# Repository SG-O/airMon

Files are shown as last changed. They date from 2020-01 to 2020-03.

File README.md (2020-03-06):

**WARNING** This is work in progress! Expect everything to be broken!

# airMon - ESP32 based air quality monitor PCB #

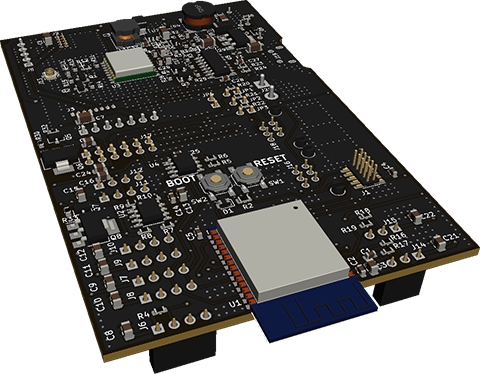
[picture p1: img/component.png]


## Features ##
### CPU ###
- Standard ESP32 WROOM module
- CH340 based USB to UART
- 802.11 b/g/n
- Bluetooth: v4.2 BR/EDR and BLE

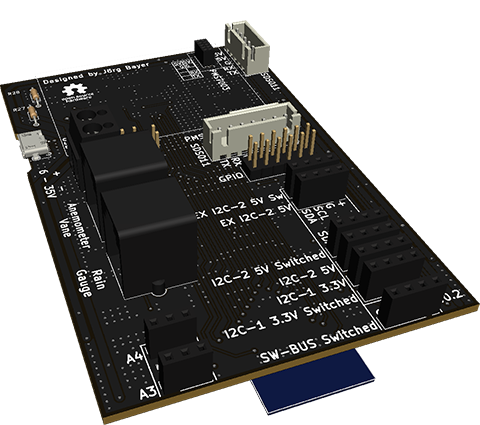
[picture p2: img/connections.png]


### IO ###
- 1 Analog IO port (0 - 12V)
- 1 Analog IO port (0 - 3.3V)
- 2 I2C buses on 4 connectors (2 of which have switchable power pins)
- 2 Additional buffered I2C connectors for longer cables (using P82B715)
- 8 GPIO
- 1 SW bus
- Dedicated connectors for several particulate matter sensors with switchable power pins
 - SDS011
 - PMS1003 - PMS6003
 - PMS7003
- Input for rainfall, wind speed and direction sensors
- GNSS support (L70/L76/MAX-M8C/MAX-M8Q/MAX-8C/MAX-8Q)
- LoRa support (RFM95/RFM96/RFM97/RFM98/RFM69)
- Input voltage measurement
- JTAG for development

### Power Supply ###
- Wide input range (6 - 35V)
- Ultra-high efficiency at light load
- Capable of 5W combined system load
- Overcurrent protection
- Customizable undervoltage protection (for battery operation)
- Switchable power outputs for high power sensors
- Reverse polarity protection

### Additional features ###
- Fits inside a 75mm waste pipe
- PMS7003 can be directly plugged into the PCB
- Active GNSS Antenna support

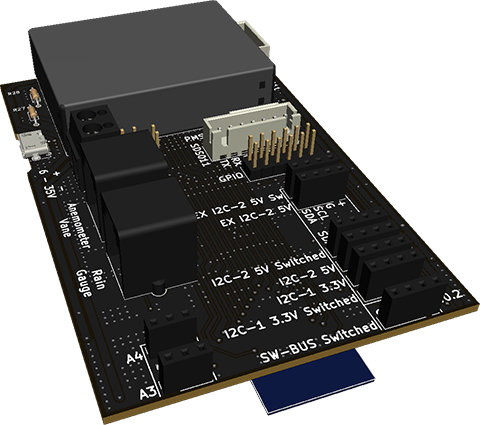
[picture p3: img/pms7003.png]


## Software ##
This was designed for the Airrohr Firmware developed by Opendata Stuttgart: [https://github.com/opendata-stuttgart/sensors-software/tree/master/airrohr-firmware](https://github.com/opendata-stuttgart/sensors-software/tree/master/airrohr-firmware)

The ESP32 support is currently experimental

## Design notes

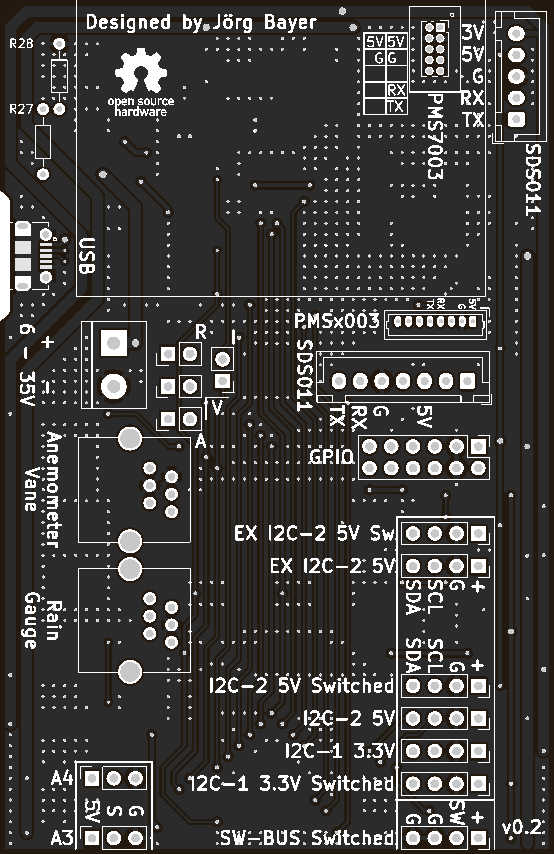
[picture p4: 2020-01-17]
img/back_nc.png

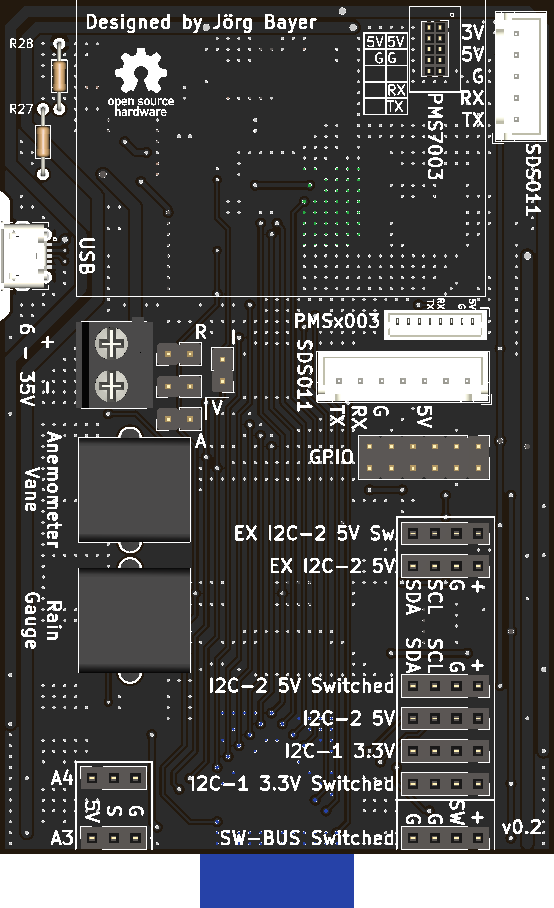
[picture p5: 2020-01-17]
img/back.png

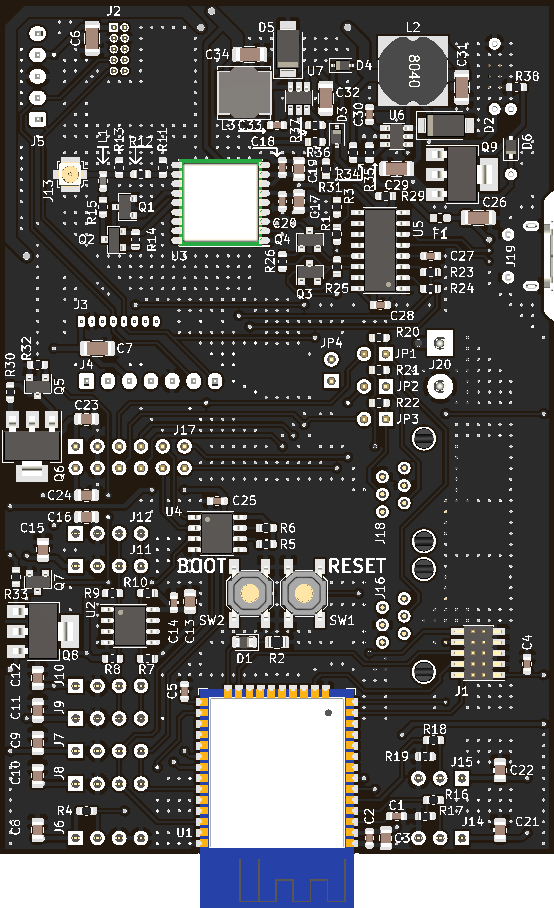
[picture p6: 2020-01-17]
img/front.png

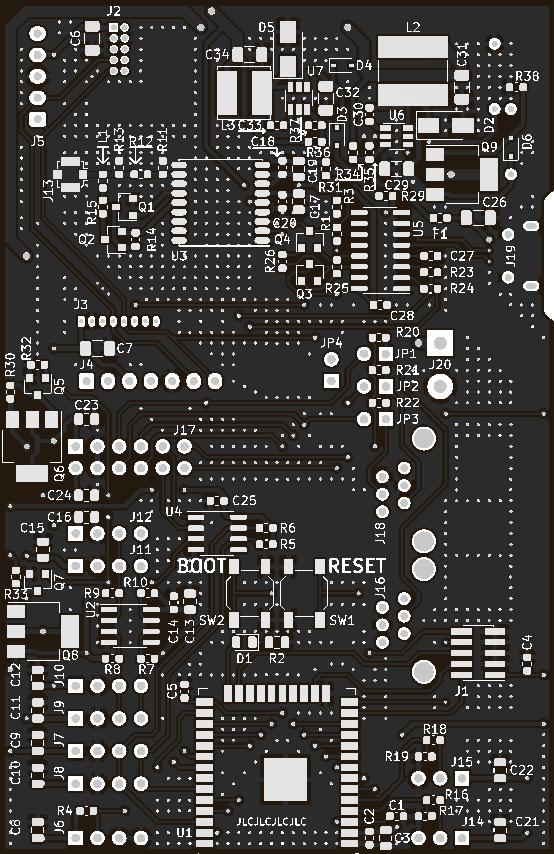
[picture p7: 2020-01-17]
img/front_nc.png

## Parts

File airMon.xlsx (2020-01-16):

Component | References | Value | Footprint | Quantity Per PCB | manf# | lcsc# | digikey#
1 | C1 C2 C4 C5 C14 C18 C20 C25 C27 C28 C30 C33 | 100n | C_0603_1608Metric | 12 | CC0603KRX7R9BB104 | C14663
2 | C6 C7 C26 C29 C31 C32 C34 | 10u | C_1206_3216Metric | 7 | CL31A106KBHNNNE | C13585
3 | C3 C8 C9 C10 C11 C12 C13 C15 C16 C17 C19 C21 C22 C23 C24 | 1u | C_0805_2012Metric | 15 | CL21B105KBFNNNE | C28323
4 | D3 D4 | BAT760-7 | D_SOD-323 | 2 | BAT760-7 | C124187
5 | D1 | GREEN | D_0805_2012Metric | 1 |  | C2297
6 | D2 D5 | SK36A-LTP | D_SMA | 2 | SK36A-LTP |  | SK36A-LTPMSCT-ND
7 | D6 | UDZVTE-1712B | D_SOD-323F | 1 | UDZVTE-1712B | C84980
8 | F1 | Polyfuse | Fuse_0603_1608Metric | 1 | 0603L050SLYR | C207014
9 | J14 | A3 | PinSocket_1x03_P2.54mm_Vertical | 1
10 | J15 | A4 | PinSocket_1x03_P2.54mm_Vertical | 1
11 | J5 | Conn_01x05 | JST_XH_B05B-XH-A_1x05_P2.50mm_Vertical | 1 | B5B-XH-A(LF)(SN) | C157991
12 | J17 | GPIO | PinHeader_2x06_P2.54mm_Vertical | 1
13 | J13 | GPS | U.FL_Molex_MCRF_73412-0110_Vertical | 1 | U.FL-R-SMT-1(80) | C88374
14 | J7 | I2C_1_1 | PinSocket_1x04_P2.54mm_Vertical | 1
15 | J8 | I2C_1_2 | PinSocket_1x04_P2.54mm_Vertical | 1
16 | J9 | I2C_2_1 | PinSocket_1x04_P2.54mm_Vertical | 1
17 | J10 | I2C_2_2 | PinSocket_1x04_P2.54mm_Vertical | 1
18 | J11 | I2C_2_3_Buffer | PinSocket_1x04_P2.54mm_Vertical | 1
19 | J12 | I2C_2_4_Buffer | PinSocket_1x04_P2.54mm_Vertical | 1
20 | J1 | JTAG | PinHeader_2x05_P1.27mm_Vertical_SMD | 1 | 20021221-00010C4LF | C180221
21 | J2 | PMS7003 | PinSocket_2x05_P1.27mm_Vertical | 1
22 | J3 | PMSx003 | Molex_PicoBlade_53047-0810_1x08_P1.25mm_Vertical | 1 | 53047-0810 | C240845
23 | J20 | Power | TerminalBlock_bornier-2_P5.08mm | 1 | WJ301V-5.0-2P | C8475
24 | J16 | Rain | DS1133-S60 | 1 | DS1133-S40BPX | C77856
25 | J4 | SDS011 | JST_XH_B07B-XH-A_1x07_P2.50mm_Vertical | 1 | B7B-XH-A(LF)(SN) | C144398
26 | J6 | SW | PinSocket_1x04_P2.54mm_Vertical | 1
27 | J19 | USB_B_Micro | USB_Micro-B_Molex-105017-0001 | 1 | 105017-0001 | C136000
28 | J18 | Wind | DS1133-S60 | 1 | DS1133-S40BPX | C77856
29 | JP1 JP2 JP3 JP4 | Jumper_NO | PinHeader_1x02_P2.54mm_Vertical | 4
30 | L3 | 15uH | L_Bourns_SRN6045TA | 1 | SRN6045-150M |  | SRN6045-150MCT-ND
31 | L2 | 22uH | L_Bourns_SRN8040 | 1 | SRN8040-220M |  | SRN8040-220MCT-ND
32 | L1 | 47n | L_0603_1608Metric | 1 | SDCL1608C47NJTDF | C29683
33 | Q1 Q5 Q7 | 2N7002 | SOT-23 | 3 | 2N7002 | C8545
34 | Q2 | AO3401A | SOT-23 | 1 | AO3401A | C15127
35 | Q6 Q8 Q9 | DMP6023LE-13 | SOT-223-3_TabPin2 | 3 | DMP6023LE-13 | C154901
36 | Q3 Q4 | SS8050 | SOT-23 | 2 | SS8050 | C2150
37 | R12 | 0R | R_0603_1608Metric | 1 | 0603WAF0000T5E | C21189
38 | R30 R32 R33 | 100k | R_0603_1608Metric | 3 | 0603WAF1003T5E | C25803
39 | R15 | 10R | R_0603_1608Metric | 1 | 0603WAF100JT5E | C22859
40 | R1 R3 R4 R14 R21 R25 R26 R31 | 10k | R_0603_1608Metric | 8 | 0603WAF1002T5E | C25804
41 | R29 R34 R36 | 110k | R_0603_1608Metric | 3 | RT0603BRD07110KL | C326736
42 | R17 R19 | 15k | R_0603_1608Metric | 2 | 0603WAF1502T5E | C22809
43 | R38 | 1M | R_0603_1608Metric | 1 | 0603WAF1004T5E | C22935
44 | R2 | 1k | R_0805_2012Metric | 1 | 0805W8F1001T5E | C17513
45 | R35 | 20k | R_0603_1608Metric | 1 | ERJPB3B2002V | C191225
46 | R9 R10 | 330R | R_0603_1608Metric | 2 | 0603WAF3300T5E | C23138
47 | R37 | 33k | R_0603_1608Metric | 1 | ERJ3RBD3302V | C416700
48 | R23 R24 | 470R | R_0603_1608Metric | 2 | 0603WAF4700T5E | C23179
49 | R16 R18 | 47k | R_0603_1608Metric | 2 | 0603WAF4702T5E | C25819
50 | R5 R6 R7 R8 R20 R22 | 4k7 | R_0603_1608Metric | 6 | 0603WAF4701T5E | C23162
53 | SW2 | Boot | SW_SPST_SKQG_WithStem | 1 | TS-1187A-C-C-B | C318889
54 | SW1 | RESET | SW_SPST_SKQG_WithStem | 1 | TS-1187A-C-C-B | C318889
55 | U5 | CH340C | SOIC-16_3.9x9.9mm_P1.27mm | 1 | CH340C | C84681
56 | U1 | ESP32-WROOM-32 | ESP32-WROOM-32 | 1 | ESP32-WROOM-32
57 | U3 | L70/L76/MAX-M8C/MAX-M8Q/MAX-8C/MAX-8Q | L70 | 1
58 | U6 U7 | LMR14010ADDCR | TSOT-23-6 | 2 | LMR14010ADDCR | C388174
59 | U2 | P82B715 | SOIC-8_3.9x4.9mm_P1.27mm | 1 | P82B715 |  | 296-24729-1-ND
60 | U4 | PCA9536D | SOIC-8_3.9x4.9mm_P1.27mm | 1 | PCA9536D | C129522

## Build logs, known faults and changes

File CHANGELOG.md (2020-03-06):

# Changelog #
## v0.3 ##

- Fixed a swapped I2C bus

## v0.2 ##

- Added RFM95 Module for Lora
- Changed input voltage monitoring from A2(IO35) to A3(IO36)
- Removed A3 12V compatibility
- Rearranged IOs to fit new components

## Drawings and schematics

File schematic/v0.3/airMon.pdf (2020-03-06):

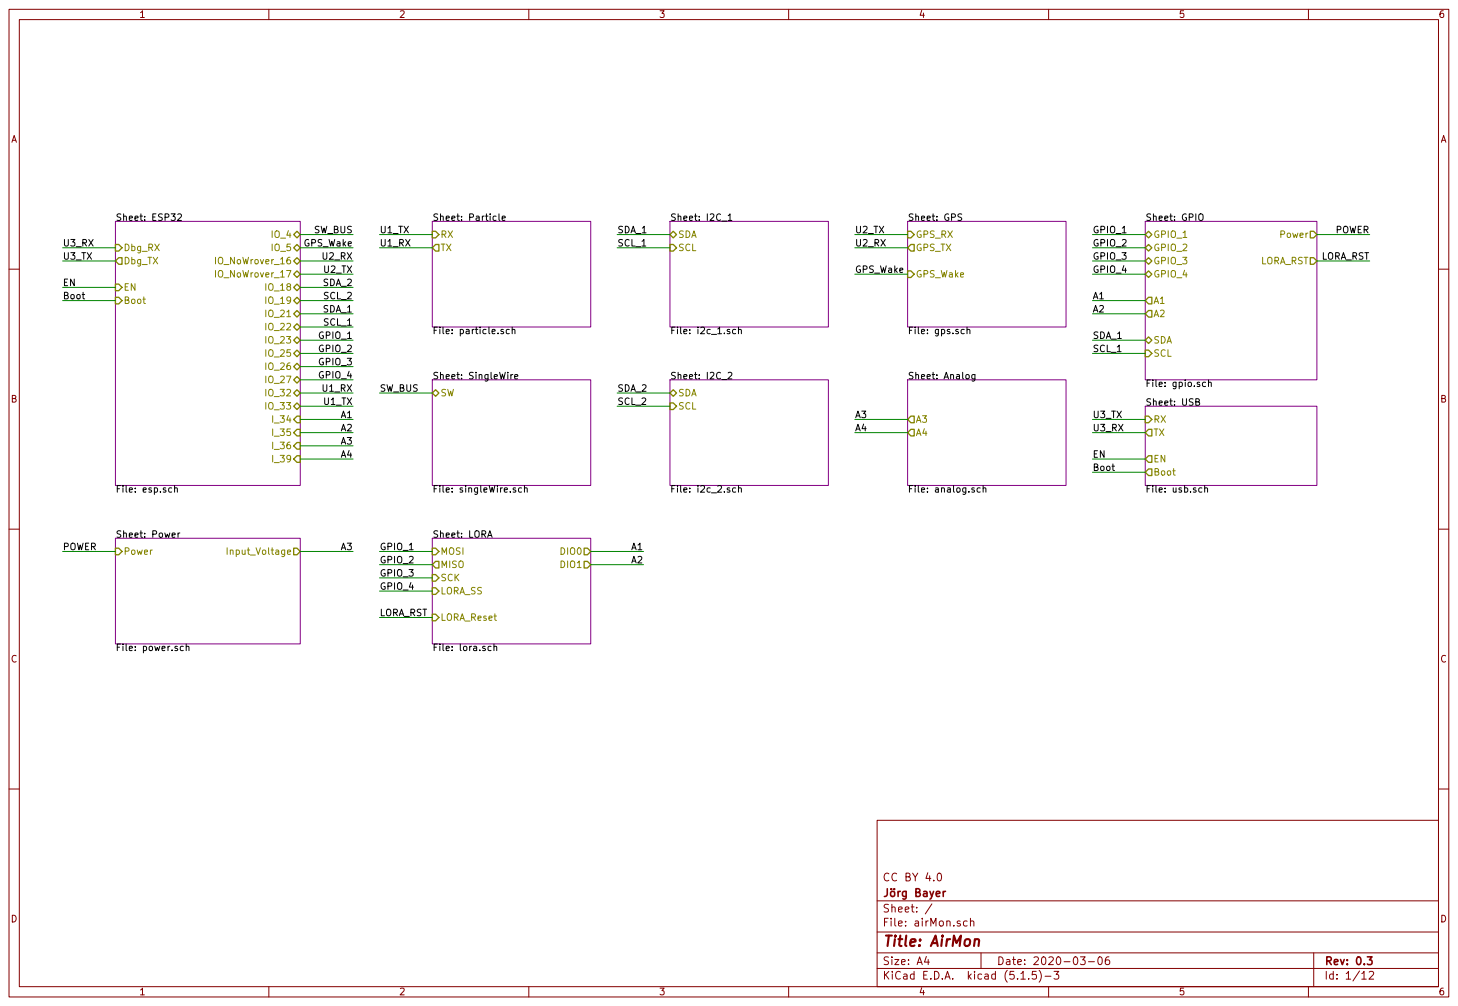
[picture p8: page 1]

Sheet: ESP32 File: esp.sch

Sheet: Particle File: particle.sch RX

Sheet: I2C_1 File: i2c_1.sch SCL SDA
File: gps.sch GPS_RX GPS_TX GPS_Wake Sheet: I2C_2 File: i2c_2.sch SCL SDA

Sheet: SingleWire
File: singleWire.sch SW

File: usb.sch EN

File: lora.sch SCK MOSI MISO

File: airMon.sch Sheet: / Jörg Bayer CC BY 4.0

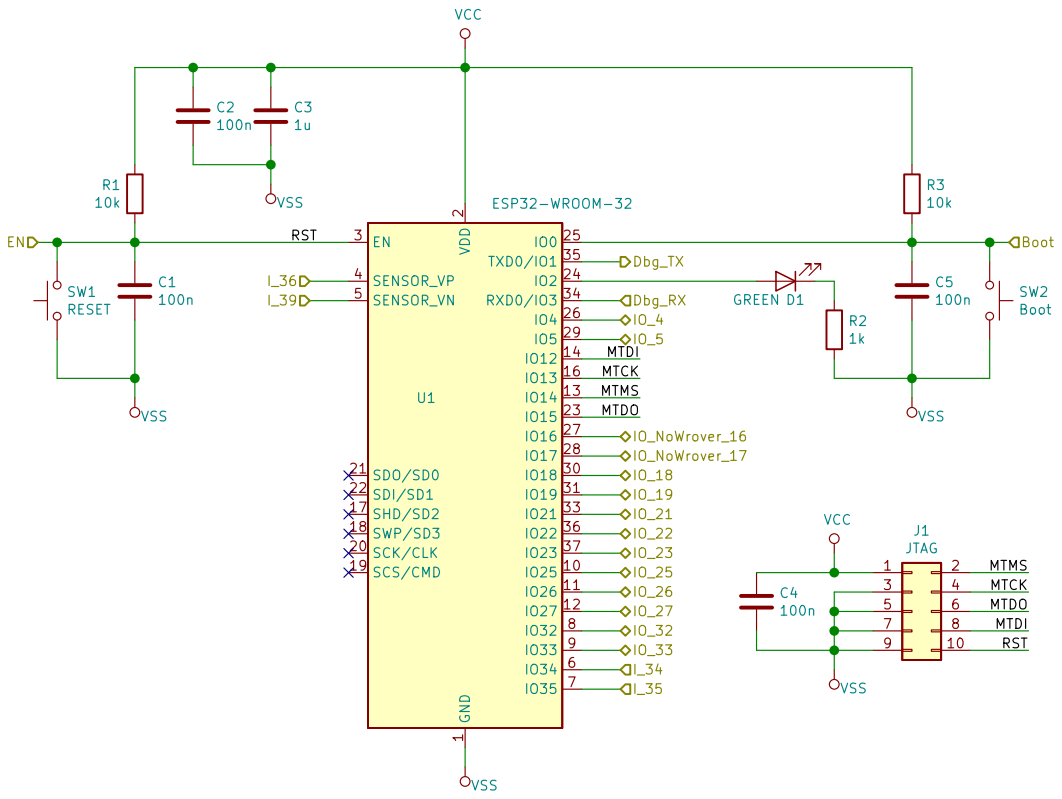
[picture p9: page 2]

2 SCK/CLK 20 SDO/SD0 21 SDI/SD1 22

File: esp.sch Sheet: /ESP32/ Jörg Bayer CC BY 4.0 C4

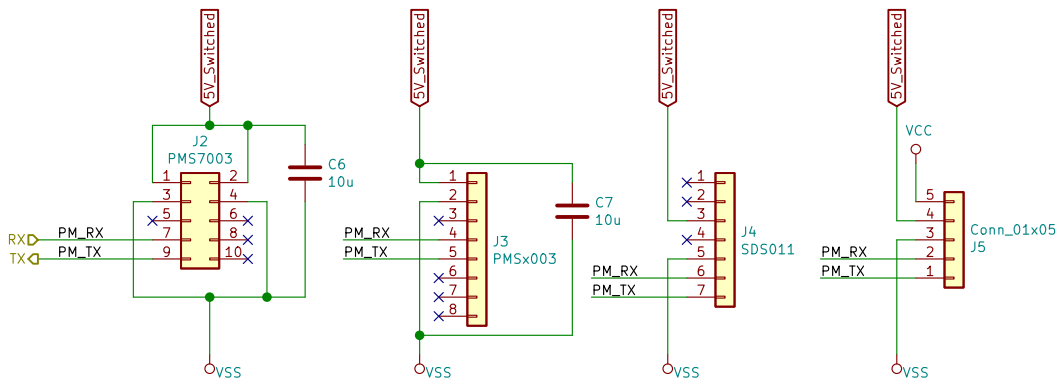
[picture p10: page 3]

File: particle.sch Sheet: /Particle/ Jörg Bayer CC BY 4.0

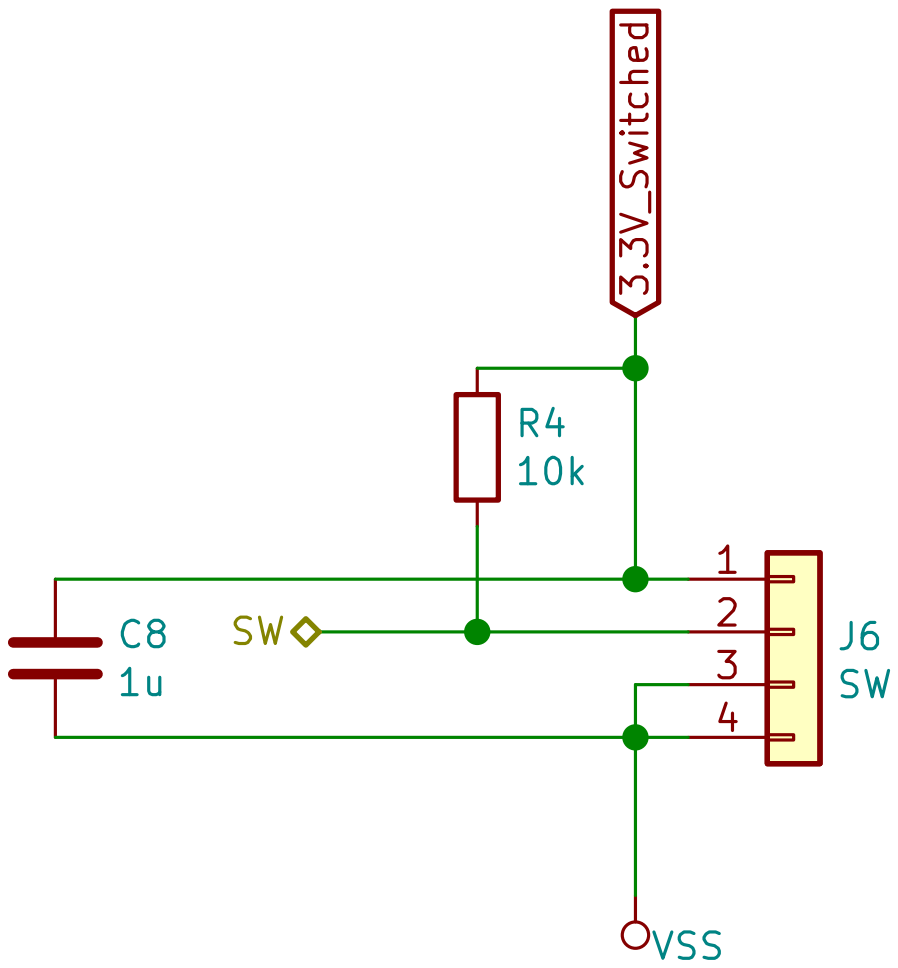
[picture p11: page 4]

Jörg Bayer CC BY 4.0

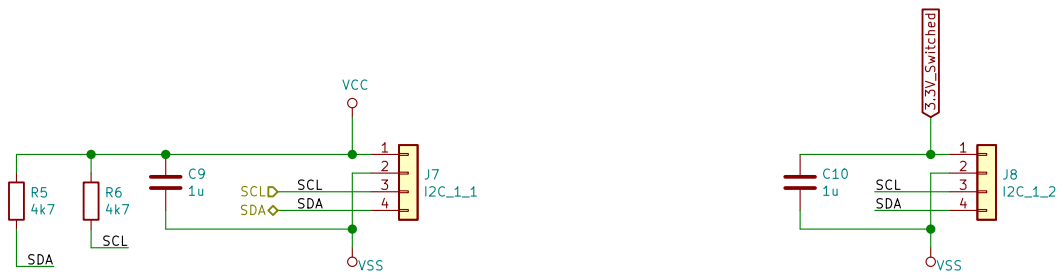
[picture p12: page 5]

Jörg Bayer CC BY 4.0

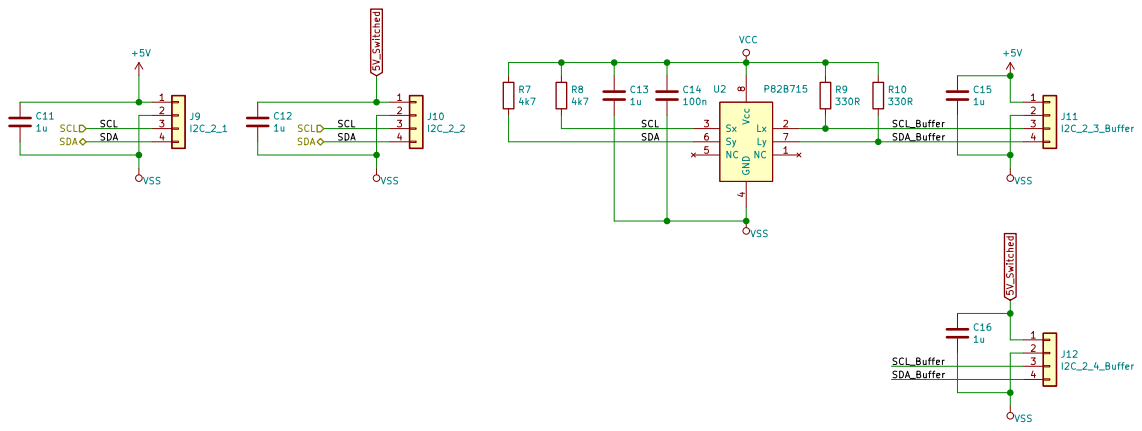
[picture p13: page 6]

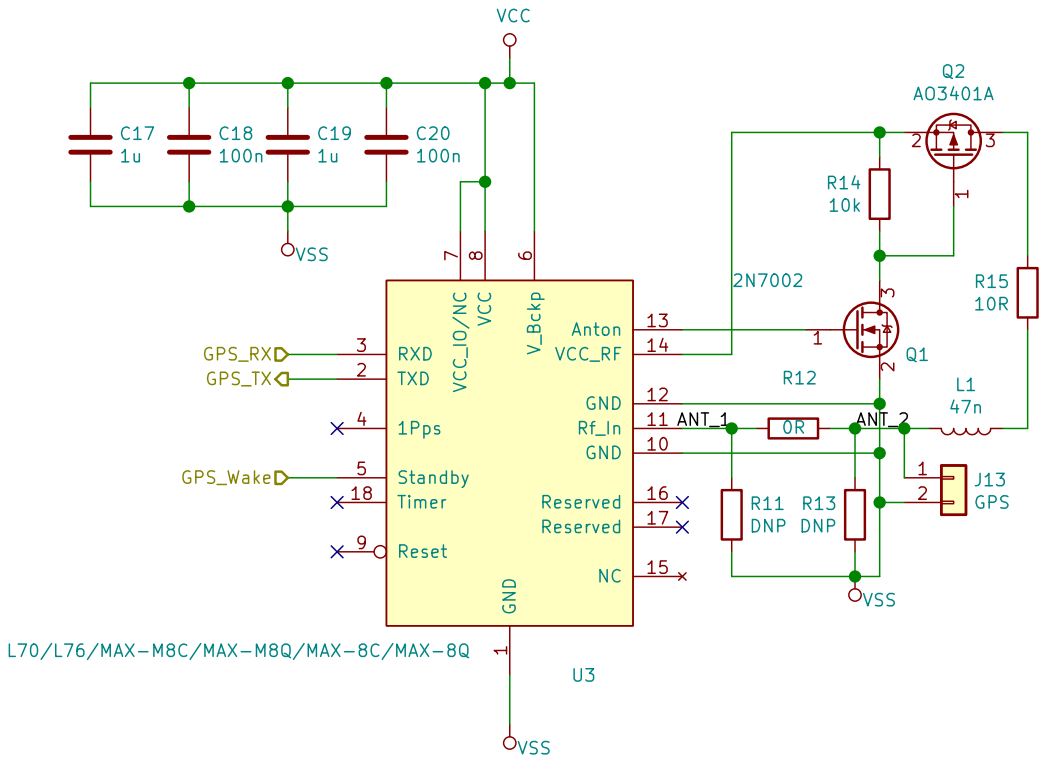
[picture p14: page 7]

File: gps.sch Sheet: /GPS/ Jörg Bayer CC BY 4.0 R13 DNP

1 GND 10 Rf_In 11 GND 12 Anton 13 VCC_RF 14 NC 15 Reserved 16 Reserved 17 Timer 18 TXD 2 RXD 3

L70/L76/MAX-M8C/MAX-M8Q/MAX-8C/MAX-8Q

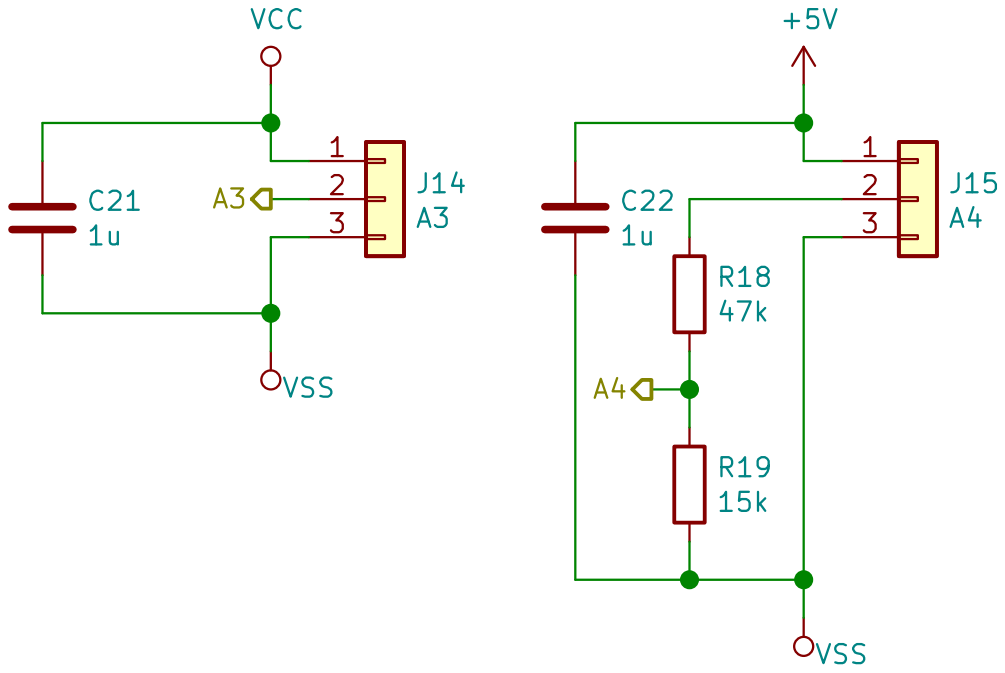
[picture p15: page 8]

Jörg Bayer CC BY 4.0

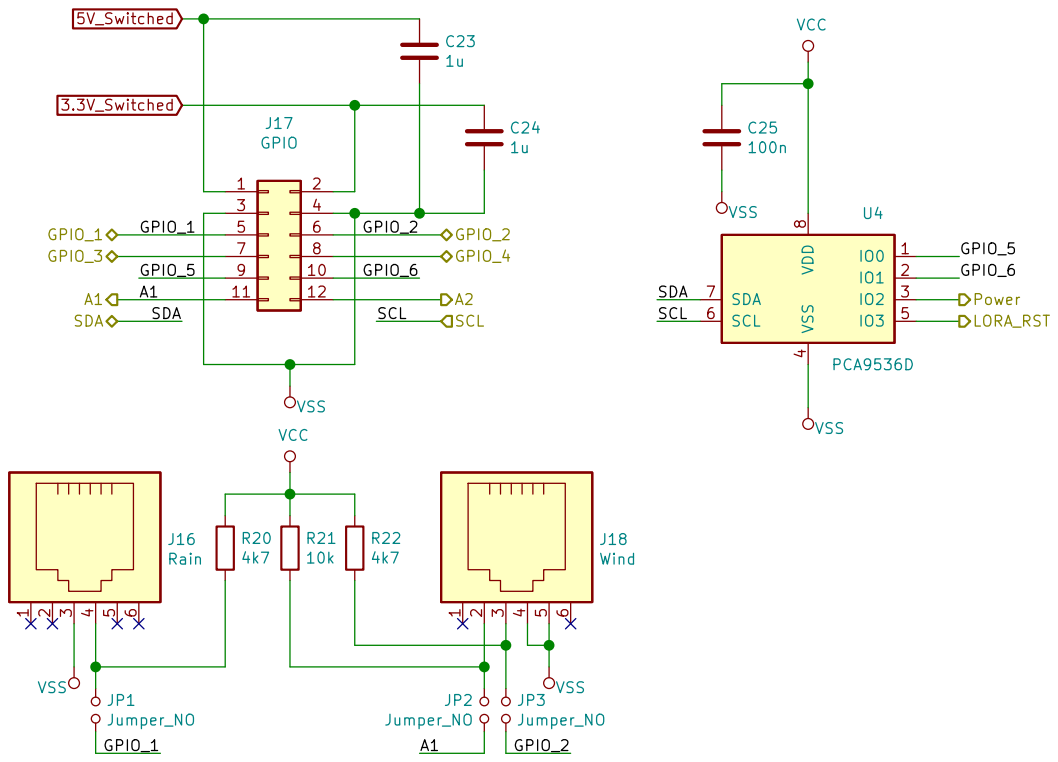
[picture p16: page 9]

9 | 10
11 | 12

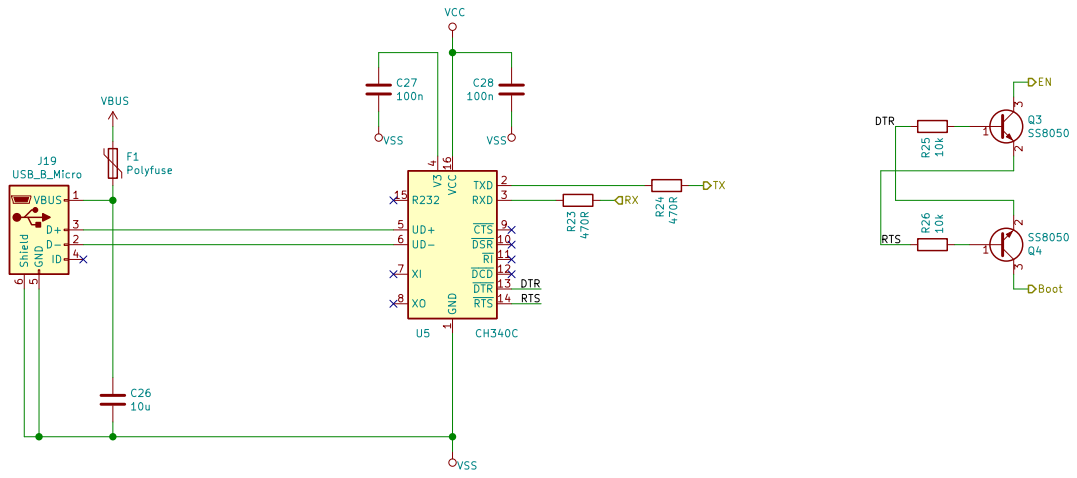
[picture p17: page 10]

1 DSR 10 RI 11 DCD 12 DTR 13 RTS 14 R232 15 VCC 16 TXD 2 RXD 3 V3

4 UD+ 5 UD- 6 XI 7 XO 8 CTS 9 U5 CH340C R24 470R R23 470R

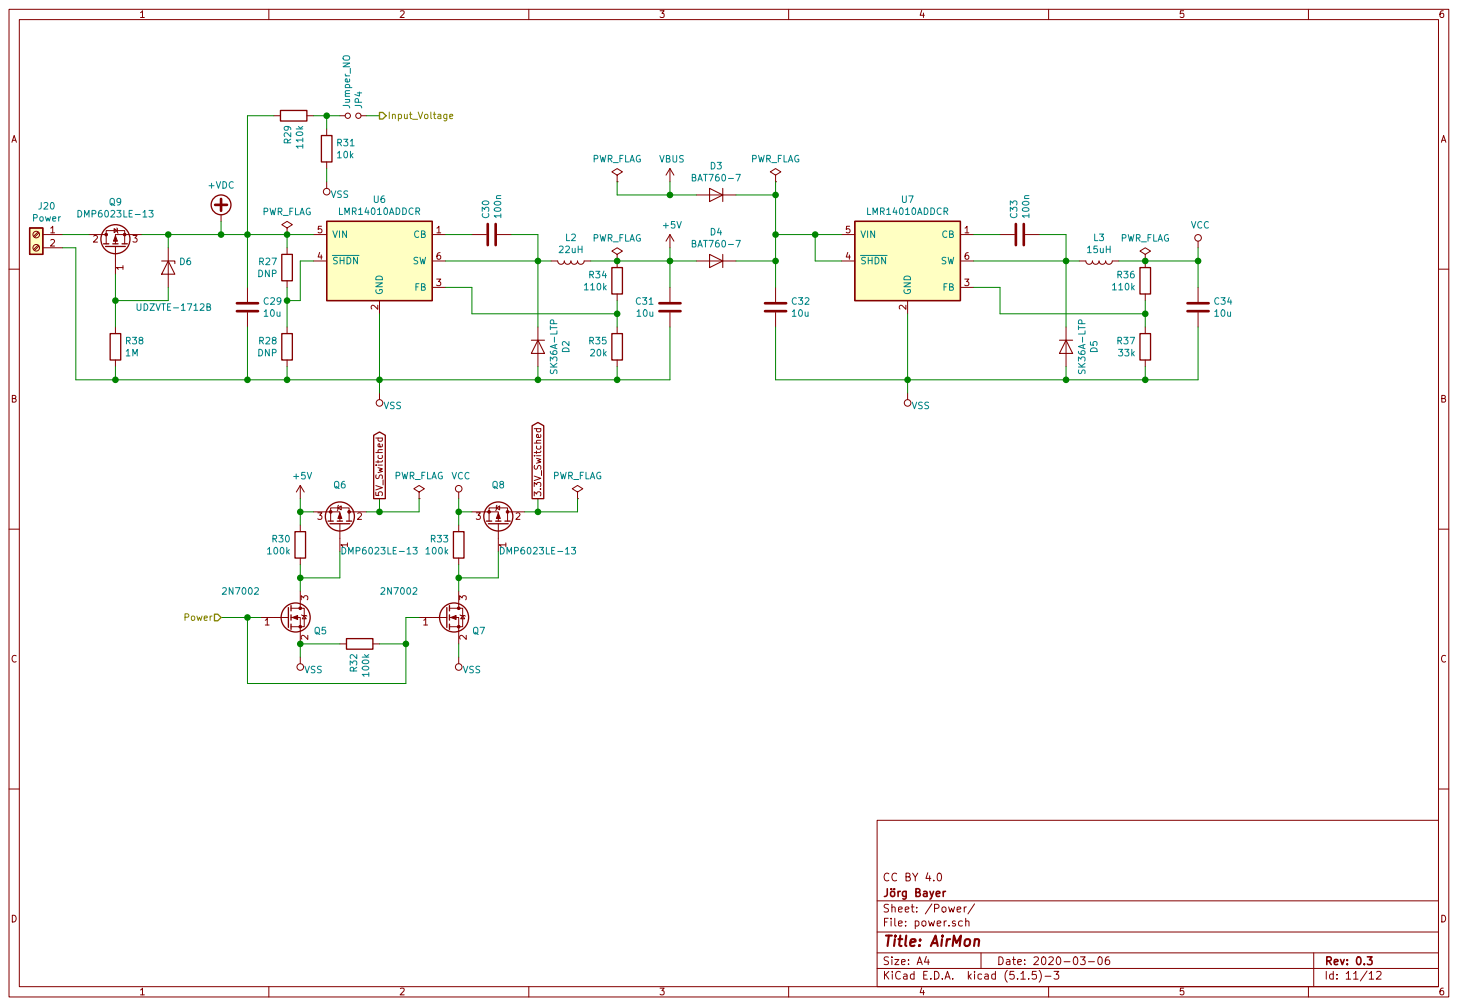
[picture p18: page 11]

2 FB 3 SHDN 4 VIN 5 SW 6 U6

2 FB 3 SHDN 4 VIN 5 SW 6 U7
LMR14010ADDCR

File: power.sch Sheet: /Power/ Jörg Bayer CC BY 4.0 PWR_FLAG

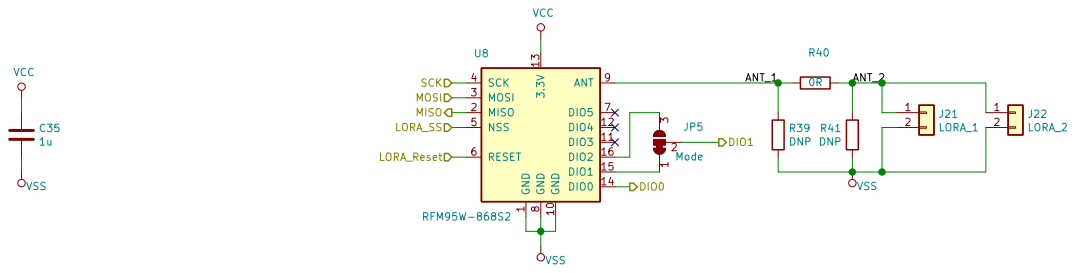
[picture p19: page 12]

1 GND 10 DIO3 11 DIO4 12 3.3V 13 DIO0 14 DIO1 15 DIO2 16 MISO 2 MOSI 3 SCK 4 NSS 5 RESET 6 DIO5 7 GND

Id: 12/12 Title: File: lora.sch Sheet: /LORA/ GND

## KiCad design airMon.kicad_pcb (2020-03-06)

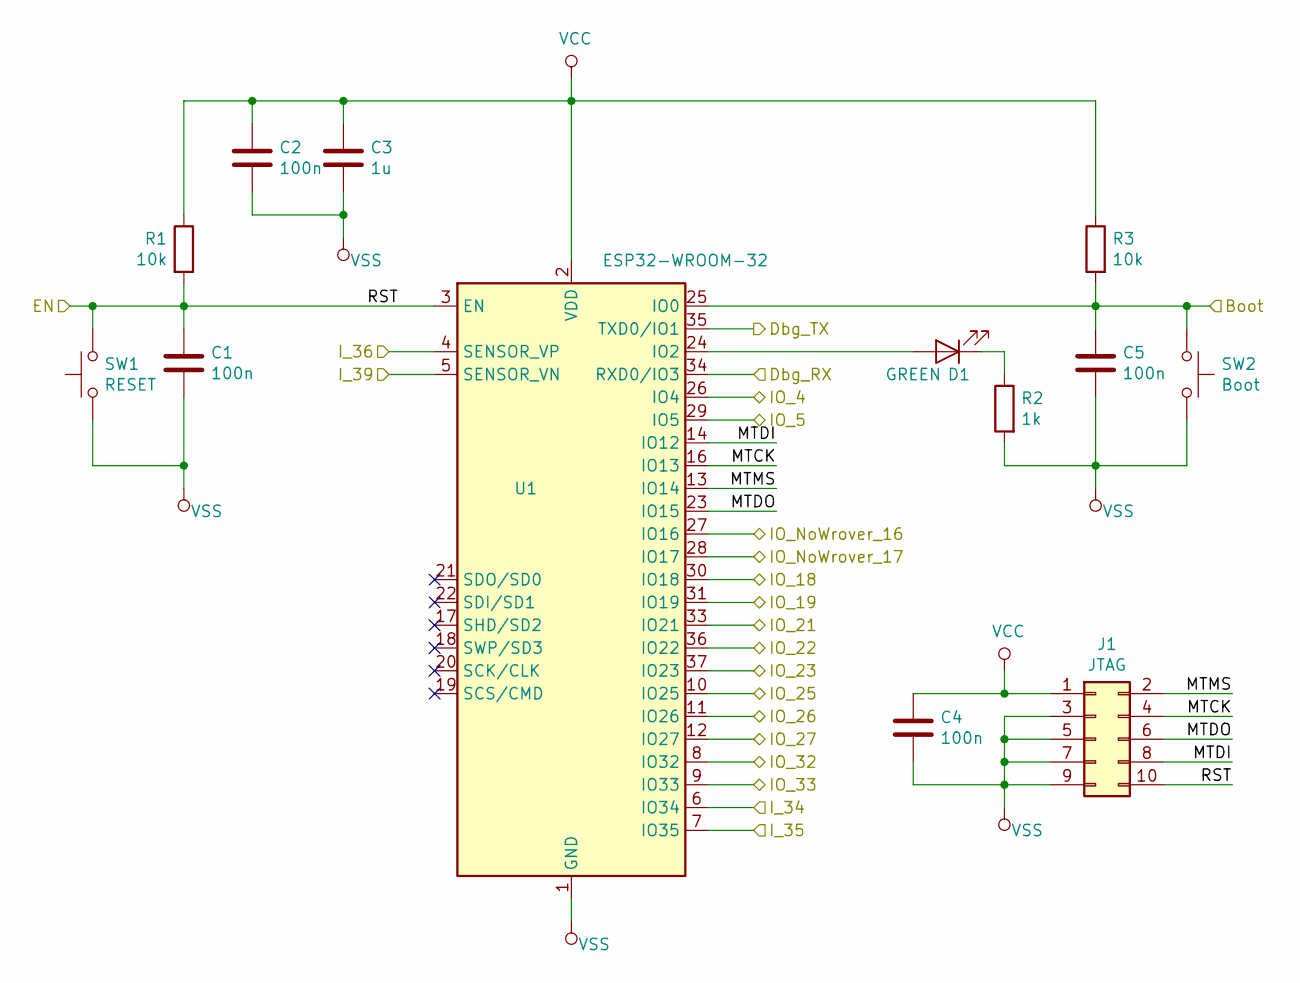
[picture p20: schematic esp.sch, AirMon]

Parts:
C1, C2, C4, C5: 100n; C_0603_1608Metric; lcsc# C14663
C3: 1u; C_0805_2012Metric; lcsc# C28323
D1: GREEN; D_0805_2012Metric; lcsc# C2297
J1: JTAG; PinHeader_2x05_P1.27mm_Vertical_SMD; lcsc# C180221
R1, R3: 10k; R_0603_1608Metric; lcsc# C25804
R2: 1k; R_0805_2012Metric; lcsc# C17513
SW1: RESET; SW_SPST_SKQG_WithStem; lcsc# C318889
SW2: Boot; SW_SPST_SKQG_WithStem; lcsc# C318889
U1: ESP32-WROOM-32

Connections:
/A1: U1.6 (IO34); also elsewhere on the board
/A2: U1.7 (IO35); also elsewhere on the board
/A3: U1.4 (SENSOR_VP); also elsewhere on the board
/A4: U1.5 (SENSOR_VN); also elsewhere on the board
/Boot: C5.1, R3.2, SW2.1, U1.25 (IO0); also elsewhere on the board
/EN: C1.1, J1.10, R1.2, SW1.1, U1.3 (EN); also elsewhere on the board
/ESP32/MTCK: J1.4, U1.16 (IO13)
/ESP32/MTDI: J1.8, U1.14 (IO12)
/ESP32/MTDO: J1.6, U1.23 (IO15)
/ESP32/MTMS: J1.2, U1.13 (IO14)
/GPIO_1: U1.37 (IO23); also elsewhere on the board
/GPIO_2: U1.10 (IO25); also elsewhere on the board
/GPIO_3: U1.11 (IO26); also elsewhere on the board
/GPIO_4: U1.12 (IO27); also elsewhere on the board
/GPS_Wake: U1.29 (IO5); also elsewhere on the board
/SCL_1: U1.36 (IO22); also elsewhere on the board
/SCL_2: U1.31 (IO19); also elsewhere on the board
/SDA_1: U1.33 (IO21); also elsewhere on the board
/SDA_2: U1.30 (IO18); also elsewhere on the board
/SW_BUS: U1.26 (IO4); also elsewhere on the board
/U1_RX: U1.8 (IO32); also elsewhere on the board
/U1_TX: U1.9 (IO33); also elsewhere on the board
/U2_RX: U1.27 (IO16); also elsewhere on the board
/U2_TX: U1.28 (IO17); also elsewhere on the board
/U3_RX: U1.34 (RXD0/IO3); also elsewhere on the board
/U3_TX: U1.35 (TXD0/IO1); also elsewhere on the board
unnamed: D1.1 (K), R2.1
unnamed: D1.2 (A), U1.24 (IO2)
VCC: C2.1, C3.1, C4.1, J1.1, R1.1, R3.1, U1.2 (VDD); also elsewhere on the board
VSS: C1.2, C2.2, C3.2, C4.2, C5.2, J1.3, J1.5, J1.7, J1.9, R2.2, SW1.2, SW2.2, U1.1 (GND), U1.15 (GND), U1.38 (GND), U1.39 (GND); also elsewhere on the board

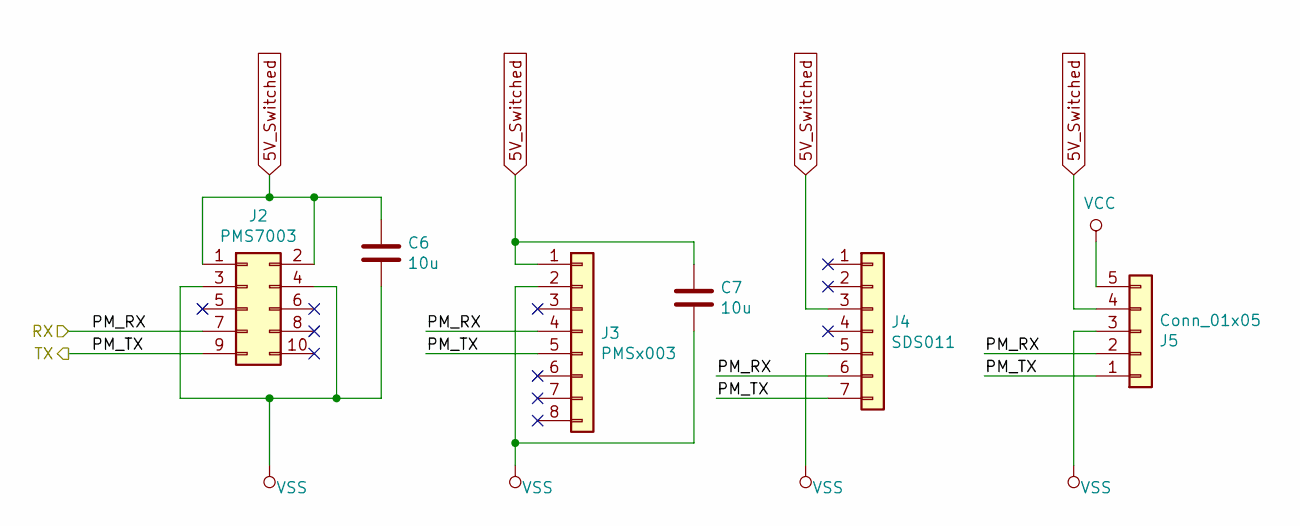
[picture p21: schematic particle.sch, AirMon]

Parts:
C6, C7: 10u; C_1206_3216Metric; lcsc# C13585
J2: PMS7003; PinSocket_2x05_P1.27mm_Vertical
J3: PMSx003; Molex_PicoBlade_53047-0810_1x08_P1.25mm_Vertical; lcsc# C240845
J4: SDS011; JST_XH_B07B-XH-A_1x07_P2.50mm_Vertical; lcsc# C144398
J5: Conn_01x05; JST_XH_B05B-XH-A_1x05_P2.50mm_Vertical; lcsc# C157991

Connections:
5V_Switched: C6.1, C7.1, J2.1, J2.2, J3.1, J4.3, J5.4; also elsewhere on the board
/U1_RX: J2.9, J3.5, J4.7, J5.1; also elsewhere on the board
/U1_TX: J2.7, J3.4, J4.6, J5.2; also elsewhere on the board
VCC: J5.5; also elsewhere on the board
VSS: C6.2, C7.2, J2.3, J2.4, J3.2, J4.5, J5.3; also elsewhere on the board

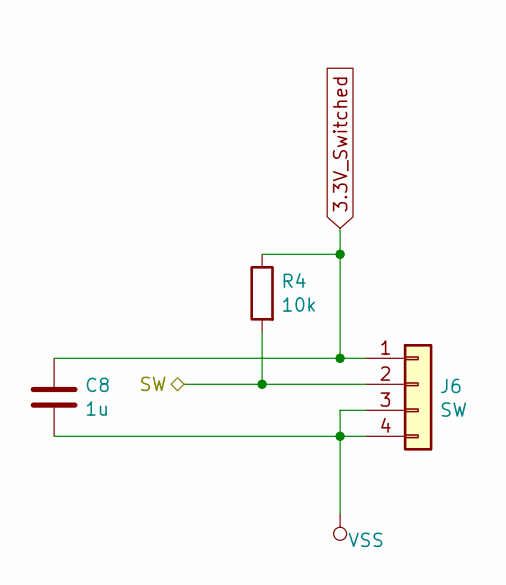
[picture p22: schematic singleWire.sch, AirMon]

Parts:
C8: 1u; C_0805_2012Metric; lcsc# C28323
J6: SW; PinSocket_1x04_P2.54mm_Vertical
R4: 10k; R_0603_1608Metric; lcsc# C25804

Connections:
3.3V_Switched: C8.1, J6.1, R4.1; also elsewhere on the board
/SW_BUS: J6.2, R4.2; also elsewhere on the board
VSS: C8.2, J6.3, J6.4; also elsewhere on the board

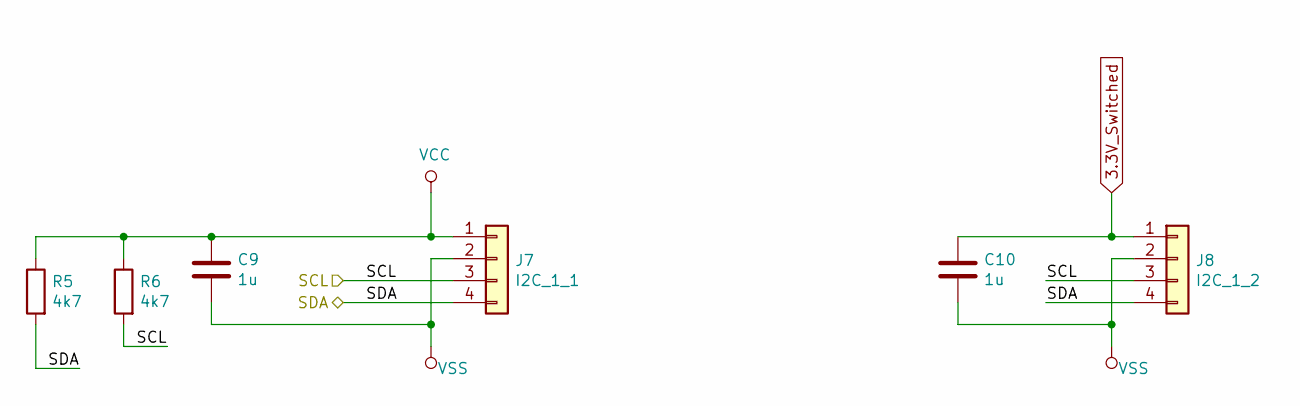
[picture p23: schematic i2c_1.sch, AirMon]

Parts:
C9, C10: 1u; C_0805_2012Metric; lcsc# C28323
J7: I2C_1_1; PinSocket_1x04_P2.54mm_Vertical
J8: I2C_1_2; PinSocket_1x04_P2.54mm_Vertical
R5, R6: 4k7; R_0603_1608Metric; lcsc# C23162

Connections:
3.3V_Switched: C10.1, J8.1; also elsewhere on the board
/SCL_1: J7.3, J8.3, R6.2; also elsewhere on the board
/SDA_1: J7.4, J8.4, R5.2; also elsewhere on the board
VCC: C9.1, J7.1, R5.1, R6.1; also elsewhere on the board
VSS: C9.2, C10.2, J7.2, J8.2; also elsewhere on the board

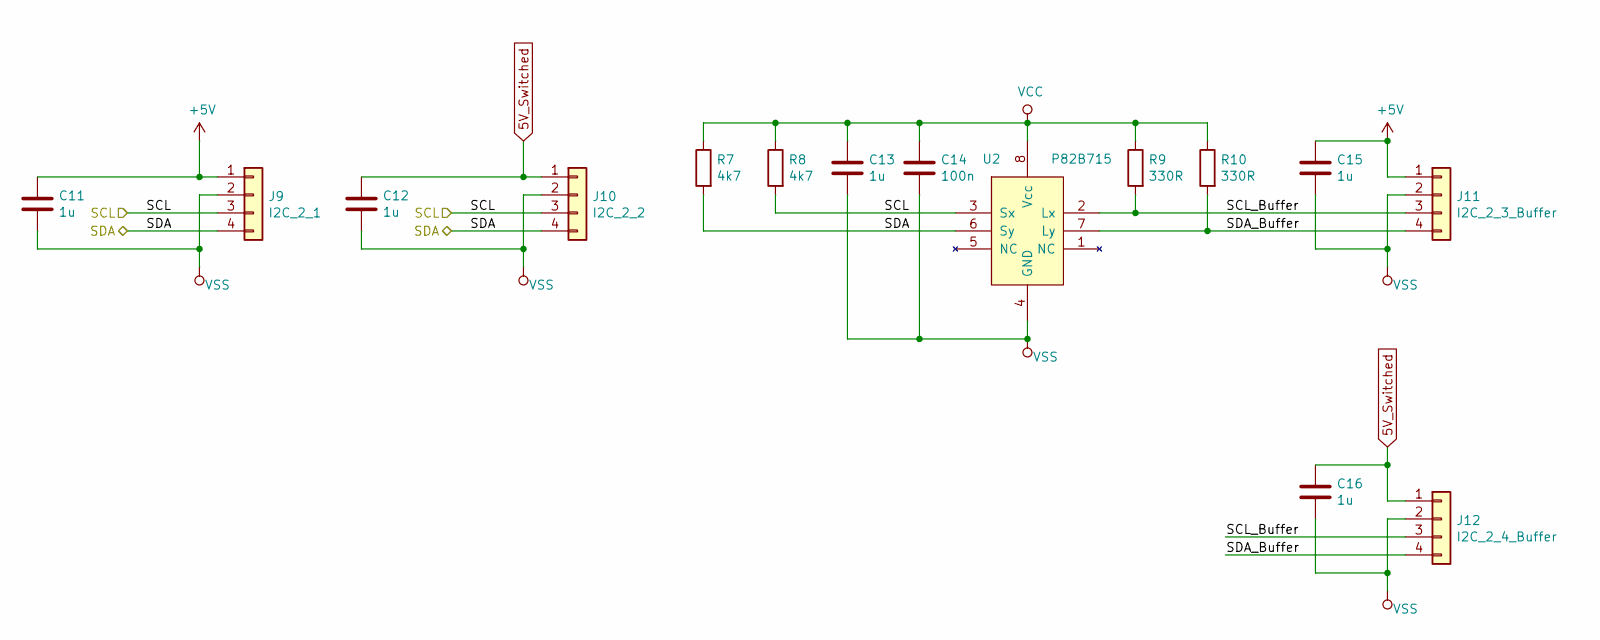
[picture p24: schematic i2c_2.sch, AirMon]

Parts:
C11, C12, C13, C15, C16: 1u; C_0805_2012Metric; lcsc# C28323
C14: 100n; C_0603_1608Metric; lcsc# C14663
J9: I2C_2_1; PinSocket_1x04_P2.54mm_Vertical
J10: I2C_2_2; PinSocket_1x04_P2.54mm_Vertical
J11: I2C_2_3_Buffer; PinSocket_1x04_P2.54mm_Vertical
J12: I2C_2_4_Buffer; PinSocket_1x04_P2.54mm_Vertical
R7, R8: 4k7; R_0603_1608Metric; lcsc# C23162
R9, R10: 330R; R_0603_1608Metric; lcsc# C23138
U2: P82B715; SOIC-8_3.9x4.9mm_P1.27mm; digikey# 296-24729-1-ND

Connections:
5V_Switched: C12.1, C16.1, J10.1, J12.1; also elsewhere on the board
+5V: C11.1, C15.1, J9.1, J11.1; also elsewhere on the board
/I2C_2/SCL_Buffer: J11.3, J12.3, R9.2, U2.2 (Lx)
/I2C_2/SDA_Buffer: J11.4, J12.4, R10.2, U2.7 (Ly)
/SCL_2: J9.3, J10.3, R8.2, U2.3 (Sx); also elsewhere on the board
/SDA_2: J9.4, J10.4, R7.2, U2.6 (Sy); also elsewhere on the board
VCC: C13.1, C14.1, R7.1, R8.1, R9.1, R10.1, U2.8 (Vcc); also elsewhere on the board
VSS: C11.2, C12.2, C13.2, C14.2, C15.2, C16.2, J9.2, J10.2, J11.2, J12.2, U2.4 (GND); also elsewhere on the board

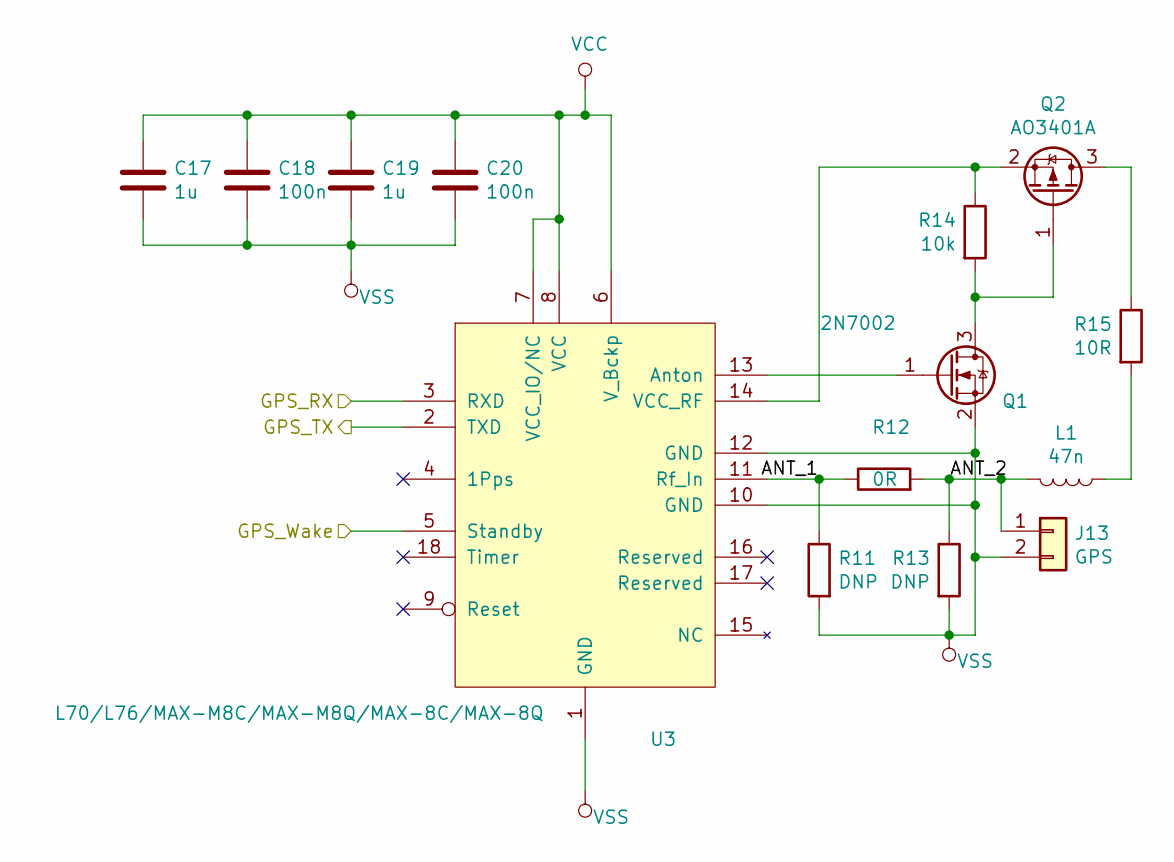
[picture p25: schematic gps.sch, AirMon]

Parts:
C17, C19: 1u; C_0805_2012Metric; lcsc# C28323
C18, C20: 100n; C_0603_1608Metric; lcsc# C14663
J13: GPS; U.FL_Molex_MCRF_73412-0110_Vertical; lcsc# C88374
L1: 47n; L_0603_1608Metric; lcsc# C29683
Q1: 2N7002; SOT-23; lcsc# C8545
Q2: AO3401A; SOT-23; lcsc# C15127
R11, R13: DNP; R_0603_1608Metric
R12: 0R; R_0603_1608Metric; lcsc# C21189
R14: 10k; R_0603_1608Metric; lcsc# C25804
R15: 10R; R_0603_1608Metric; lcsc# C22859
U3: L70/L76/MAX-M8C/MAX-M8Q/MAX-8C/MAX-8Q; L70

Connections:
/GPS/ANT_1: R11.1, R12.1, U3.11 (Rf_In)
/GPS/ANT_2: J13.1, L1.2, R12.2, R13.1
/GPS_Wake: U3.5 (Standby); also elsewhere on the board
/U2_RX: U3.2 (TXD); also elsewhere on the board
/U2_TX: U3.3 (RXD); also elsewhere on the board
unnamed: L1.1, R15.2
unnamed: Q1.1 (G), U3.13 (Anton)
unnamed: Q1.3 (D), Q2.1 (G), R14.2
unnamed: Q2.2 (S), R14.1, U3.14 (VCC_RF)
unnamed: Q2.3 (D), R15.1
VCC: C17.1, C18.1, C19.1, C20.1, U3.6 (V_Bckp), U3.7 (VCC_IO/NC), U3.8 (VCC); also elsewhere on the board
VSS: C17.2, C18.2, C19.2, C20.2, J13.2, Q1.2 (S), R11.2, R13.2, U3.1 (GND), U3.10 (GND), U3.12 (GND); also elsewhere on the board

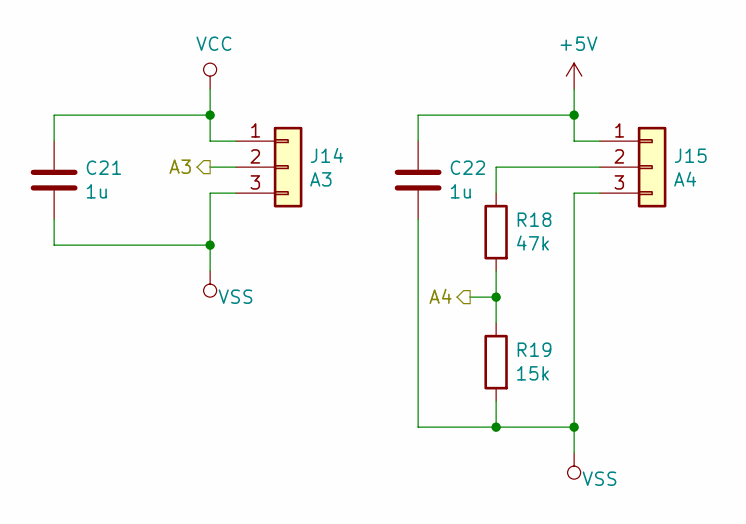
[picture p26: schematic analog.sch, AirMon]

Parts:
C21, C22: 1u; C_0805_2012Metric; lcsc# C28323
J14: A3; PinSocket_1x03_P2.54mm_Vertical
J15: A4; PinSocket_1x03_P2.54mm_Vertical
R18: 47k; R_0603_1608Metric; lcsc# C25819
R19: 15k; R_0603_1608Metric; lcsc# C22809

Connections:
+5V: C22.1, J15.1; also elsewhere on the board
/A3: J14.2; also elsewhere on the board
/A4: R18.2, R19.1; also elsewhere on the board
unnamed: J15.2, R18.1
VCC: C21.1, J14.1; also elsewhere on the board
VSS: C21.2, C22.2, J14.3, J15.3, R19.2; also elsewhere on the board

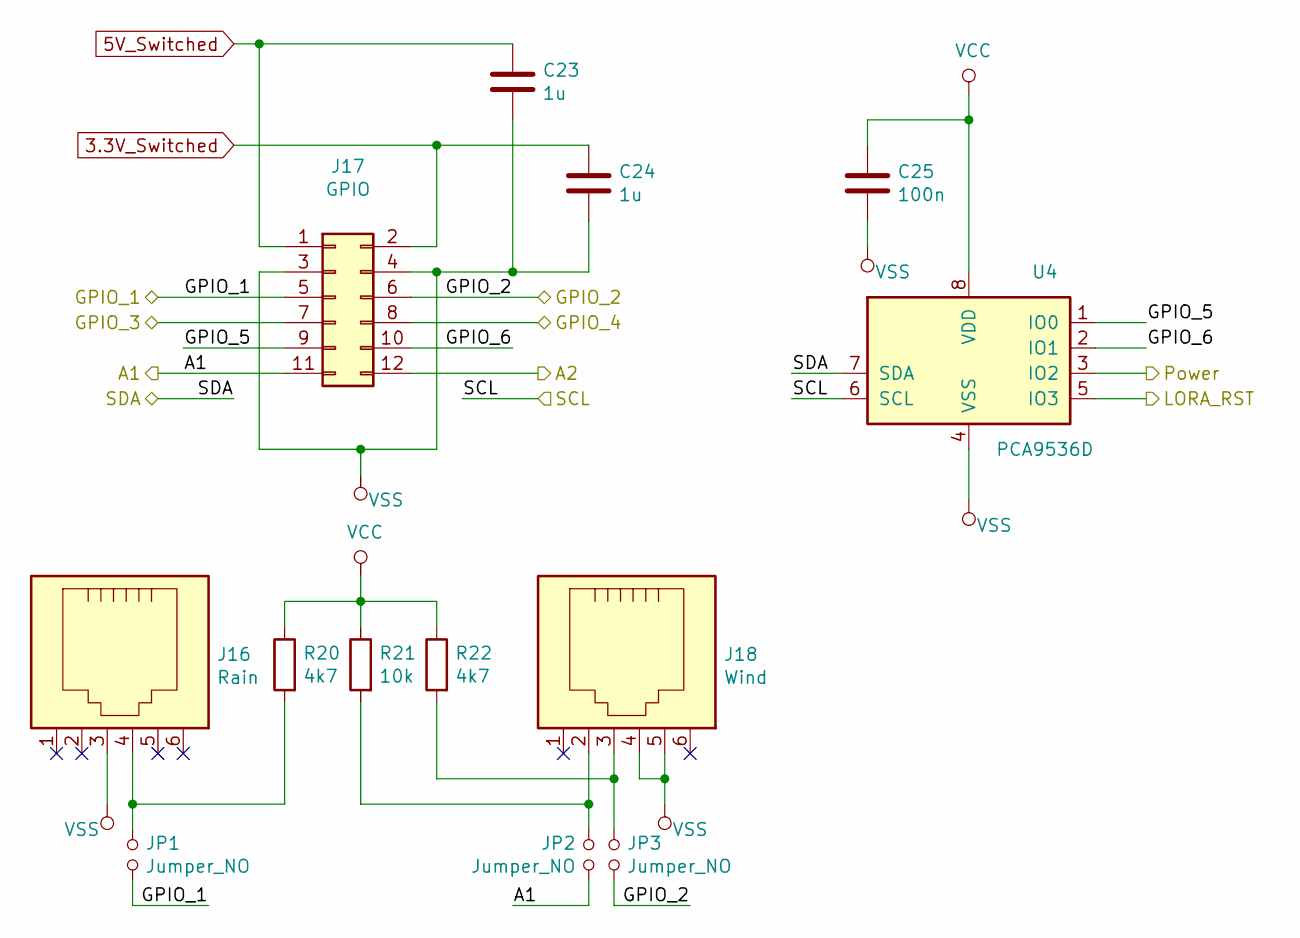
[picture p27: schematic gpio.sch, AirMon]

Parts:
C23, C24: 1u; C_0805_2012Metric; lcsc# C28323
C25: 100n; C_0603_1608Metric; lcsc# C14663
J16: Rain; DS1133-S60; lcsc# C77856
J17: GPIO; PinHeader_2x06_P2.54mm_Vertical
J18: Wind; DS1133-S60; lcsc# C77856
JP1, JP2, JP3: Jumper_NO; PinHeader_1x02_P2.54mm_Vertical
R20, R22: 4k7; R_0603_1608Metric; lcsc# C23162
R21: 10k; R_0603_1608Metric; lcsc# C25804
U4: PCA9536D; SOIC-8_3.9x4.9mm_P1.27mm; lcsc# C129522

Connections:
3.3V_Switched: C24.1, J17.2; also elsewhere on the board
5V_Switched: C23.1, J17.1; also elsewhere on the board
/A1: J17.11, JP2.2; also elsewhere on the board
/A2: J17.12; also elsewhere on the board
/GPIO/GPIO_5: J17.9, U4.1 (IO0)
/GPIO/GPIO_6: J17.10, U4.2 (IO1)
/GPIO_1: J17.5, JP1.2; also elsewhere on the board
/GPIO_2: J17.6, JP3.2; also elsewhere on the board
/GPIO_3: J17.7; also elsewhere on the board
/GPIO_4: J17.8; also elsewhere on the board
/LORA_RST: U4.5 (IO3); also elsewhere on the board
/POWER: U4.3 (IO2); also elsewhere on the board
/SCL_1: U4.6 (SCL); also elsewhere on the board
/SDA_1: U4.7 (SDA); also elsewhere on the board
unnamed: J16.4, JP1.1, R20.2
unnamed: J18.2, JP2.1, R21.2
unnamed: J18.3, JP3.1, R22.2
VCC: C25.1, R20.1, R21.1, R22.1, U4.8 (VDD); also elsewhere on the board
VSS: C23.2, C24.2, C25.2, J16.3, J17.3, J17.4, J18.4, J18.5, U4.4 (VSS); also elsewhere on the board

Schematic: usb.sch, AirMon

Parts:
C26: 10u; C_1206_3216Metric; lcsc# C13585
C27, C28: 100n; C_0603_1608Metric; lcsc# C14663
F1: Polyfuse; Fuse_0603_1608Metric; lcsc# C207014
J19: USB_B_Micro; USB_Micro-B_Molex-105017-0001; lcsc# C136000
Q3, Q4: SS8050; SOT-23; lcsc# C2150
R23, R24: 470R; R_0603_1608Metric; lcsc# C23179
R25, R26: 10k; R_0603_1608Metric; lcsc# C25804
U5: CH340C; SOIC-16_3.9x9.9mm_P1.27mm; lcsc# C84681

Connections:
/Boot: Q4.3 (C); also elsewhere on the board
/EN: Q3.3 (C); also elsewhere on the board
/U3_RX: R24.2; also elsewhere on the board
/U3_TX: R23.2; also elsewhere on the board
/USB/DTR: Q4.2 (E), R25.1, U5.13 (~DTR)
/USB/RTS: Q3.2 (E), R26.1, U5.14 (~RTS)
unnamed: C26.1, F1.2, J19.1 (VBUS)
unnamed: C27.1, U5.4 (V3)
unnamed: J19.2 (D-), U5.6 (UD-)
unnamed: J19.3 (D+), U5.5 (UD+)
unnamed: Q3.1 (B), R25.2
unnamed: Q4.1 (B), R26.2
unnamed: R23.1, U5.3 (RXD)
unnamed: R24.1, U5.2 (TXD)
VBUS: F1.1; also elsewhere on the board
VCC: C28.1, U5.16 (VCC); also elsewhere on the board
VSS: C26.2, C27.2, C28.2, J19.5 (GND), J19.6 (Shield), U5.1 (GND); also elsewhere on the board

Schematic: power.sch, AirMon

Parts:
C29, C31, C32, C34: 10u; C_1206_3216Metric; lcsc# C13585
C30, C33: 100n; C_0603_1608Metric; lcsc# C14663
D2, D5: SK36A-LTP; D_SMA; digikey# SK36A-LTPMSCT-ND
D3, D4: BAT760-7; D_SOD-323; lcsc# C124187
D6: UDZVTE-1712B; D_SOD-323F; lcsc# C84980
J20: Power; TerminalBlock_bornier-2_P5.08mm; lcsc# C8475
JP4: Jumper_NO; PinHeader_1x02_P2.54mm_Vertical
L2: 22uH; L_Bourns_SRN8040; digikey# SRN8040-220MCT-ND
L3: 15uH; L_Bourns_SRN6045TA; digikey# SRN6045-150MCT-ND
Q5, Q7: 2N7002; SOT-23; lcsc# C8545
Q6, Q8, Q9: DMP6023LE-13; SOT-223-3_TabPin2; lcsc# C154901
R27, R28: DNP; R_Axial_DIN0204_L3.6mm_D1.6mm_P7.62mm_Horizontal
R29, R34, R36: 110k; R_0603_1608Metric; lcsc# C326736
R30, R32, R33: 100k; R_0603_1608Metric; lcsc# C25803
R31: 10k; R_0603_1608Metric; lcsc# C25804
R35: 20k; R_0603_1608Metric; lcsc# C191225
R37: 33k; R_0603_1608Metric; lcsc# C416700
R38: 1M; R_0603_1608Metric; lcsc# C22935
U6, U7: LMR14010ADDCR; TSOT-23-6; lcsc# C388174

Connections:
3.3V_Switched: Q8.2 (D); also elsewhere on the board
5V_Switched: Q6.2 (D); also elsewhere on the board
+5V: C31.1, D4.2 (A), L2.1, Q6.3 (S), R30.1, R34.1; also elsewhere on the board
+VDC: C29.1, D6.1 (K), Q9.3 (S), R27.1, R29.1, U6.5 (VIN)
/A3: JP4.1; also elsewhere on the board
/POWER: Q5.1 (G), Q7.1 (G), R32.2; also elsewhere on the board
unnamed: C30.1, U6.1 (CB)
unnamed: C30.2, D2.1 (K), L2.2, U6.6 (SW)
unnamed: C32.1, D3.1 (K), D4.1 (K), U7.4 (~SHDN), U7.5 (VIN)
unnamed: C33.1, U7.1 (CB)
unnamed: C33.2, D5.1 (K), L3.2, U7.6 (SW)
unnamed: D6.2 (A), Q9.1 (G), R38.1
unnamed: J20.1, Q9.2 (D)
unnamed: JP4.2, R29.2, R31.1
unnamed: Q5.3 (D), Q6.1 (G), R30.2
unnamed: Q7.3 (D), Q8.1 (G), R33.2
unnamed: R27.2, R28.1, U6.4 (~SHDN)
unnamed: R34.2, R35.1, U6.3 (FB)
unnamed: R36.2, R37.1, U7.3 (FB)
VBUS: D3.2 (A); also elsewhere on the board
VCC: C34.1, L3.1, Q8.3 (S), R33.1, R36.1; also elsewhere on the board
VSS: C29.2, C31.2, C32.2, C34.2, D2.2 (A), D5.2 (A), J20.2, Q5.2 (S), Q7.2 (S), R28.2, R31.2, R32.1, R35.2, R37.2, R38.2, U6.2 (GND), U7.2 (GND); also elsewhere on the board

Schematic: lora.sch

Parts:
C35: 1u; C_0805_2012Metric; lcsc# C28323
J21: LORA_1; U.FL_Molex_MCRF_73412-0110_Vertical; lcsc# C88374
J22: LORA_2; PinHeader_1x02_P1.27mm_Vertical
JP5: Mode; SolderJumper-3_P1.3mm_Bridged12_RoundedPad1.0x1.5mm_NumberL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
R39, R41: DNP; R_0603_1608Metric
R40: 0R; R_0603_1608Metric; lcsc# C21189
U8: RFM95W-868S2; HOPERF_RFM9XW_SMD

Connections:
/A1: U8.14 (DIO0); also elsewhere on the board
/A2: JP5.2 (C); also elsewhere on the board
/GPIO_1: U8.3 (MOSI); also elsewhere on the board
/GPIO_2: U8.2 (MISO); also elsewhere on the board
/GPIO_3: U8.4 (SCK); also elsewhere on the board
/GPIO_4: U8.5 (NSS); also elsewhere on the board
/LORA/ANT_1: R39.1, R40.1, U8.9 (ANT)
/LORA/ANT_2: J21.1, J22.1, R40.2, R41.1
/LORA_RST: U8.6 (RESET); also elsewhere on the board
unnamed: JP5.1 (A), U8.15 (DIO1)
unnamed: JP5.3 (B), U8.16 (DIO2)
VCC: C35.1, U8.13 (3.3V); also elsewhere on the board
VSS: C35.2, J21.2, J22.2, R39.2, R41.2, U8.1 (GND), U8.8 (GND), U8.10 (GND); also elsewhere on the board

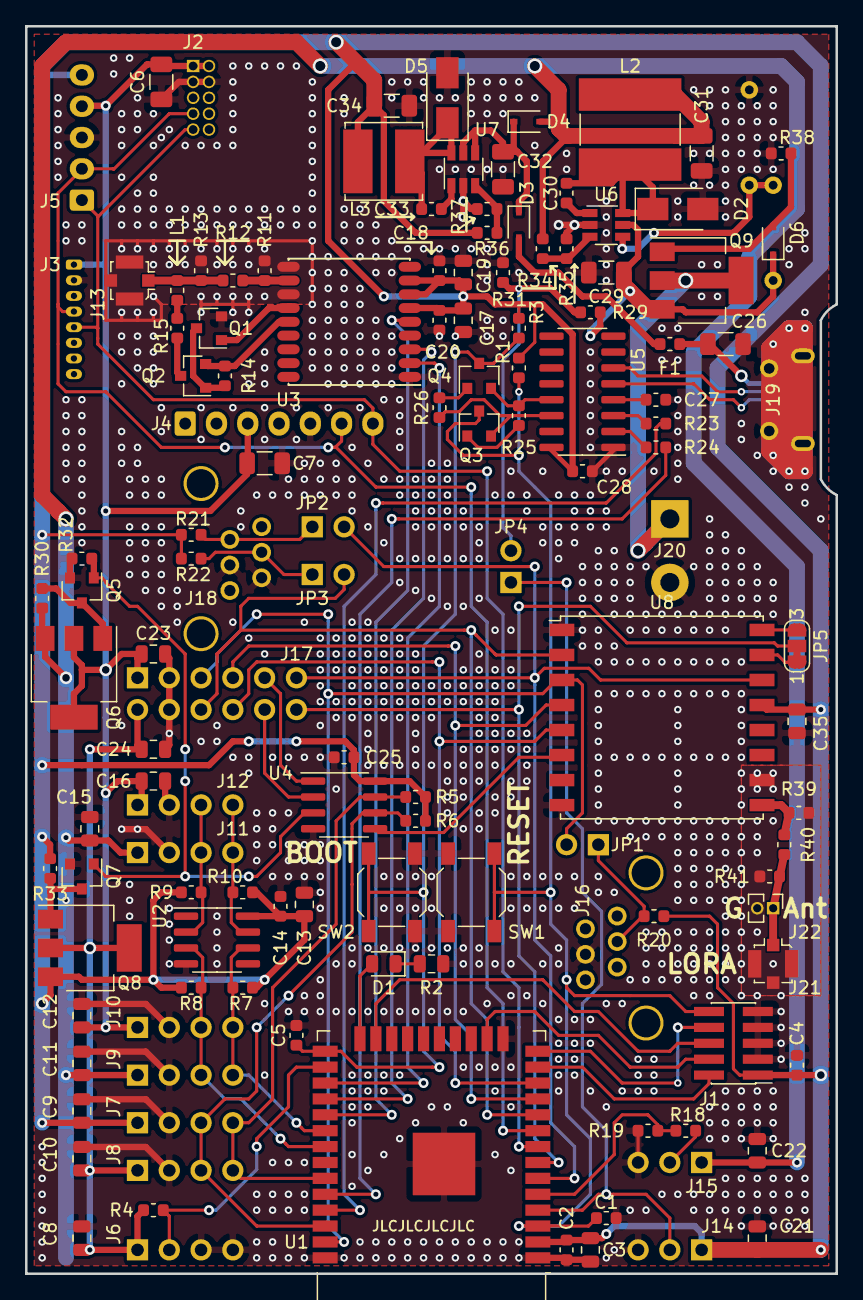
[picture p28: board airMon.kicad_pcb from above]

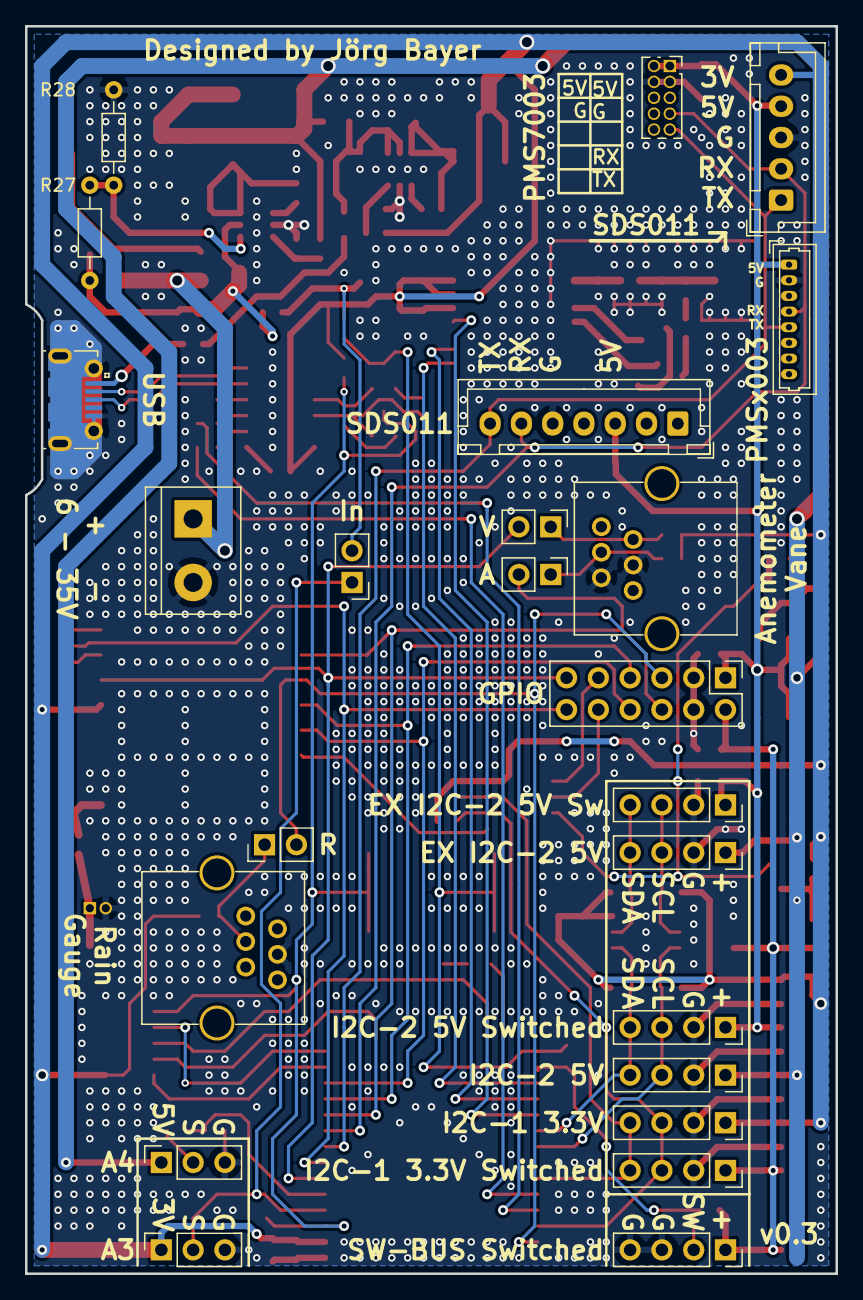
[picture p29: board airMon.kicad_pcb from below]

Board: 2 copper layers, 64.8 x 99.7 mm, 130 parts (24 on the bottom side), 79 nets.

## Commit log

2020-01-13 Added images Added information to schematic Added information to layout
    [airMon.kicad_pcb, airMon.sch, analog.sch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]
2020-01-14 Added Readme Added GNSS receiver list Fixed GNSS receiver connections Improved Pictures
    [airMon.kicad_pcb, gps.sch]
2020-01-14 Added gerber files Added schematic pdf
    [airMon-B.Cu.gbr, airMon-B.Mask.gbr, airMon-B.Paste.gbr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]
2020-01-14 Added reverse polarity protection Improved power switch mosfets
    [airMon.kicad_pcb, power.sch]
2020-01-14 Added reverse polarity protection Changed power switch MOSFETs to a lower RDS(on) model Improved buck converter layout Improved USB layout
    [airMon-B.Cu.gbr, airMon-B.Mask.gbr, airMon-B.Paste.gbr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]
2020-01-15 Fixed reverse polarity protection
    [airMon-B.Cu.gbr, airMon-B.Mask.gbr, airMon-B.Paste.gbr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]
2020-01-16 Added fuse for USB Added buttons for boot and reset Added version number to PCB Changed several component values for improved manufacturing Added BOM Added component position file
    [airMon-B.Cu.gbr, airMon-B.Mask.gbr, airMon-B.Paste.gbr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]
2020-01-16 Moved to KiCad 5.1.5_3
    [airMon-B.Cu.gbr, airMon-B.Mask.gbr, airMon-B_Cu.gbr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]
2020-01-17 Start of v0.2 Updated footprints
    [airMon.kicad_pcb, airMon.sch, analog.sch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]
2020-01-17 Made PMS7003 footprint virtual
    [airMon.kicad_pcb]
2020-01-19 Added RFM95 Module for Lora Added Changelog Changed input voltage monitoring from A2(IO35) to A3(IO36) Removed A3 12V compatibility Rearranged IOs to fit new components
    [airMon.kicad_pcb, airMon.sch, analog.sch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]
2020-01-19 Added updated schematic Added updated gerber Updated date
    [airMon-B_Cu.gbr, airMon-B_Mask.gbr, airMon-B_Paste.gbr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]
2020-03-06 Swaped two wrong I2C signals.
    [airMon-B_Cu.gbr, airMon-B_Mask.gbr, airMon-B_Paste.gbr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]
